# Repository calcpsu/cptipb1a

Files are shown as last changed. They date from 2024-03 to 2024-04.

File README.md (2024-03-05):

# CalcPack TI BP1A

A Li-Po battery replacement design for TI BP1A battery pack calculators - primarily TI-59. The original batteries had ~ 500mAh capacity (@3.6V: 1.8Wh), while modern Ni-MH replacements are typically ~1500mAh (@3.6V: 5.4Wh).

Li-Po has the advantage of far reduced self-discharge in comparison to Ni-MH, which is an advantage for an intermittently-used device. Even with similar mAh capacity, we can expect longer battery life.

Ni-MH / Ni-CD batteries are notorious for leaking. While Lithium Ion batteries are notorious for self-immolation, a well protected Li-Po battery (particularly in a low current application like this) should be able to be made very safe.

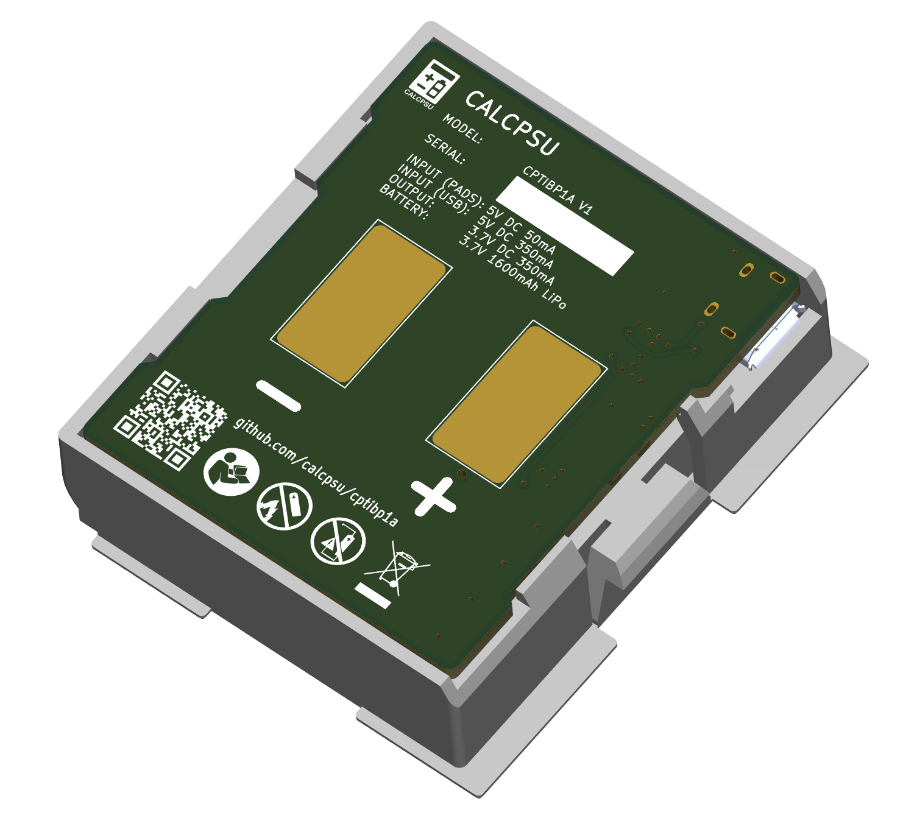
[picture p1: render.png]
Render of calcpack PCB


## Features / design goals:
- Direct replacement for a BP1A battery pack
- Compatible with existing charging circuit (although at a slow charge rate)
    - Provides adequate smoothing of rectified AC
    - Provides voltage clamping
- USB charging (when removed from calculator) at faster rate
- Protected from:
    - Overvoltage (USB and pads) at 2x rated voltage and current (IATA requirement)
    - Overcharging (4.2V)
    - Over-discharge (3.1V shutdown, 2.5V cutoff in battery pack)
    - Short circuit and overcurrent (again for IATA requirement)
- Minimum idle/quiescent current to maximise charge time
- Capable of operating TI-59 including card reader
- Similar or higher capacity than typical Ni-MH altenative (1500mAh @ 3.7V [5.55Wh])
  
## License

This work is licensed under a
[Creative Commons Attribution-NonCommercial-ShareAlike 4.0 International License][cc-by-nc-sa].

[][cc-by-nc-sa]

[cc-by-nc-sa]: http://creativecommons.org/licenses/by-nc-sa/4.0/
[cc-by-nc-sa-image]: https://licensebuttons.net/l/by-nc-sa/4.0/88x31.png
[cc-by-nc-sa-shield]: https://img.shields.io/badge/License-CC%20BY--NC--SA%204.0-lightgrey.svg

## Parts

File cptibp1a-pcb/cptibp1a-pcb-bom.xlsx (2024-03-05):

Id | Designator | Footprint | Quantity | Designation | Supplier and ref | Column1 | _1 | MPN
1 | U1 | SOT-23-5_TI_DBV5 | 1 | NCP360SNT |  |  |  | NCP360SNT1G
2 | F1 | Fuse_1210_3225Metric | 1 | 0ZCJ0050AF2E |  |  |  | 0ZCJ0050AF2E
3 | Q2 | SOT-23 | 1 | AO3413 |  |  |  | AO3413
4 | C6,C7 | CP_Elec_8x10.5 | 2 | 1000u/10V |  |  |  | EEE-FT1A102GP
5 | D2 | LED_0805_2012Metric | 1 | RED |  |  |  | B1701USD-20D000114U1930
6 | Q1 | SOT-23 | 1 | 2N7002 |  |  |  | DMG2302U-7
7 | C4 | C_0805_2012Metric | 1 | 4u7 |  |  |  | CL21A475KAQNNNE
8 | R2 | R_0805_2012Metric | 1 | 1k8
9 | R4 | R_0805_2012Metric | 1 | 3k |  |  |  | RC0805FR-073KL
10 | R5,R1 | R_0805_2012Metric | 2 | 10k |  |  |  | RC0805FR-0710KL
11 | C1 | C_0805_2012Metric | 1 | 1u |  |  |  | CL21B105KAFNNNE
12 | U5 | SOT-23-5_TI_DBV5 | 1 | MAX40203AUK |  |  |  | MAX40203AUK+T
13 | U3 | SOT-23-6_TI_DBV6 | 1 | BQ21040 |  |  |  | BQ21040DBVR
14 | D1 | D_SOD-123 | 1 | PMEG40T10ERX |  |  |  | PMEG40T10ERX
15 | J1 | AMPHENOL_10118194-0001LF | 1 | 10118194-0001LF |  |  |  | 10118194-0001LF
16 | C2 | C_0805_2012Metric | 1 | 10u |  |  |  | CL21A106KAYNNNE
17 | BT1 | JST_SH_BM03B-SRSS-TB_1x03-1MP_P1.00mm_Vertical | 1 | LiPo |  |  |  | BM03B-SRSS-TB
18 | U2 | SOT-23-3 | 1 | APX809S-31SA |  |  |  | APX809S-31SA-7
19 | R3 | R_0805_2012Metric | 1 | 8k66 |  |  |  | RC0805FR-078K66L
20 | U4 | SOT-23-3 | 1 | APX810S-44SA |  |  |  | APX810S-44SA
21 | D3 | D_SMA | 1 | 5V6/3W |  |  |  | 3SMAJ5919B-TP
22 | J3 | PAD_6x15 | 1 | PAD-
23 | J2 | PAD_6x15 | 1 | PAD+

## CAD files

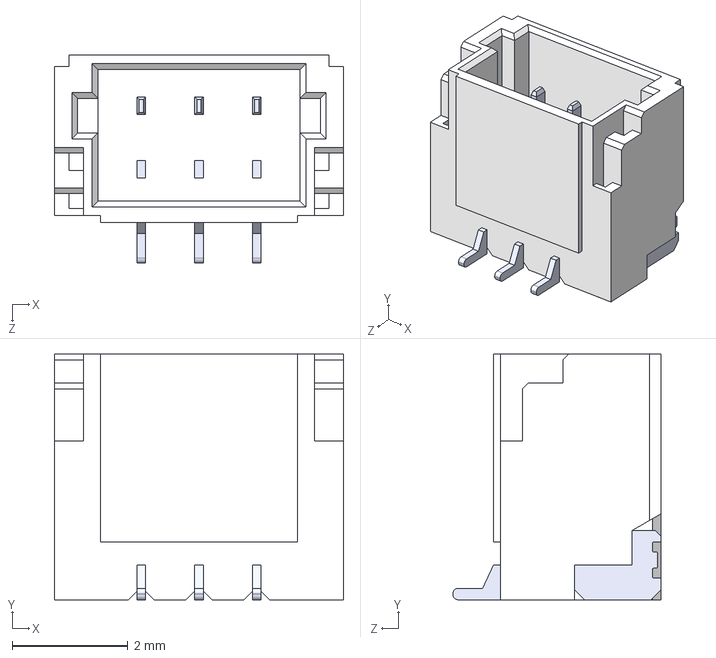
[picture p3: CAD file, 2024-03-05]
cptibp1a-pcb/3d/BM03B-SRSS-TB.STEP
5.00 x 4.25 x 3.60 mm

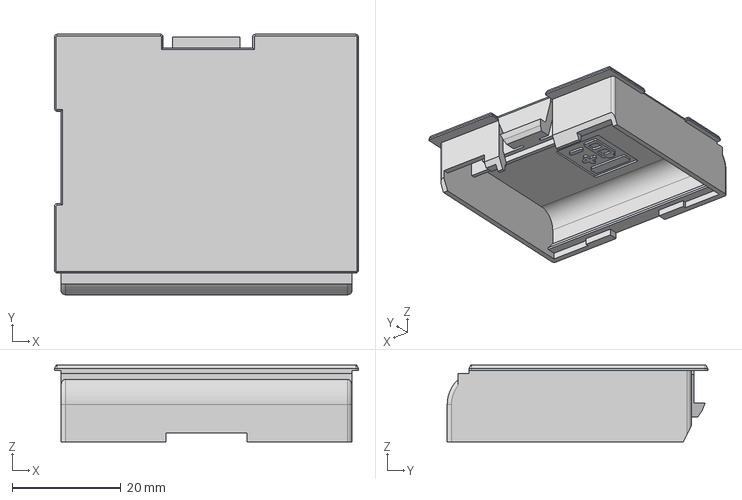
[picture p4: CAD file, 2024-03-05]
cptibp1a-pcb/cptibp1a-enclosure.step
56.0 x 48.0 x 14.1 mm

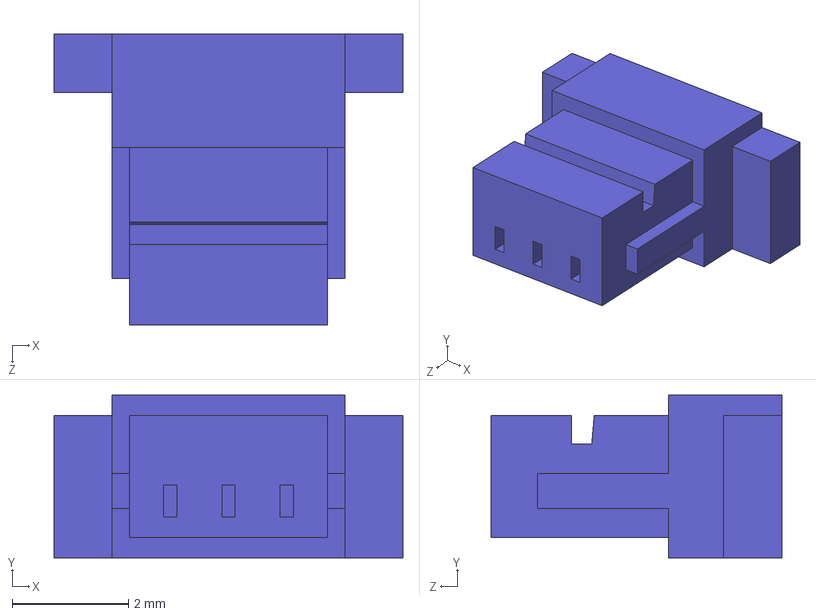
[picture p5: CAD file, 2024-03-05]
cptibp1a-pcb/3d/SHR-03V-S-B.STEP
6.00 x 2.80 x 5.00 mm

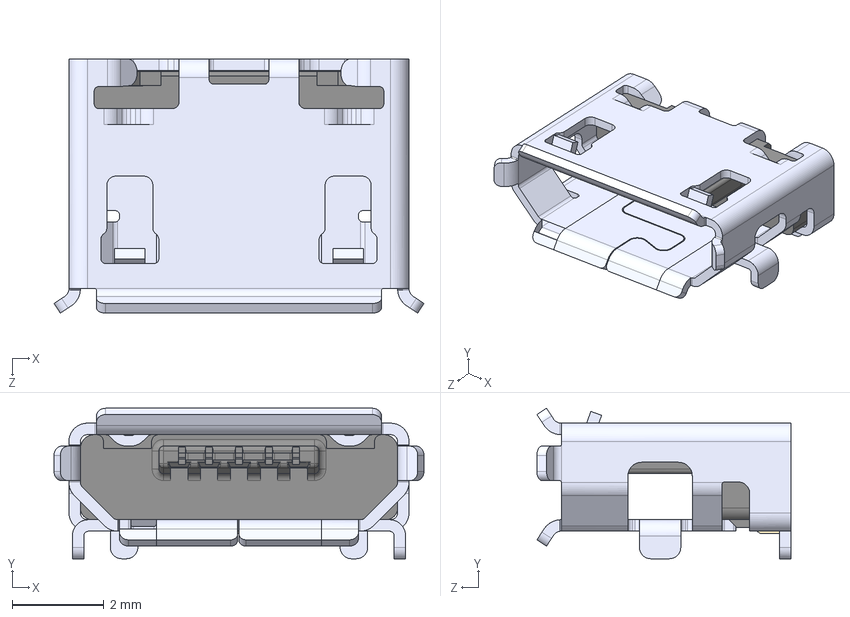
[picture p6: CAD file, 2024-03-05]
cptibp1a-pcb/3d/10118194-0001LF.step
8.05 x 3.27 x 5.53 mm

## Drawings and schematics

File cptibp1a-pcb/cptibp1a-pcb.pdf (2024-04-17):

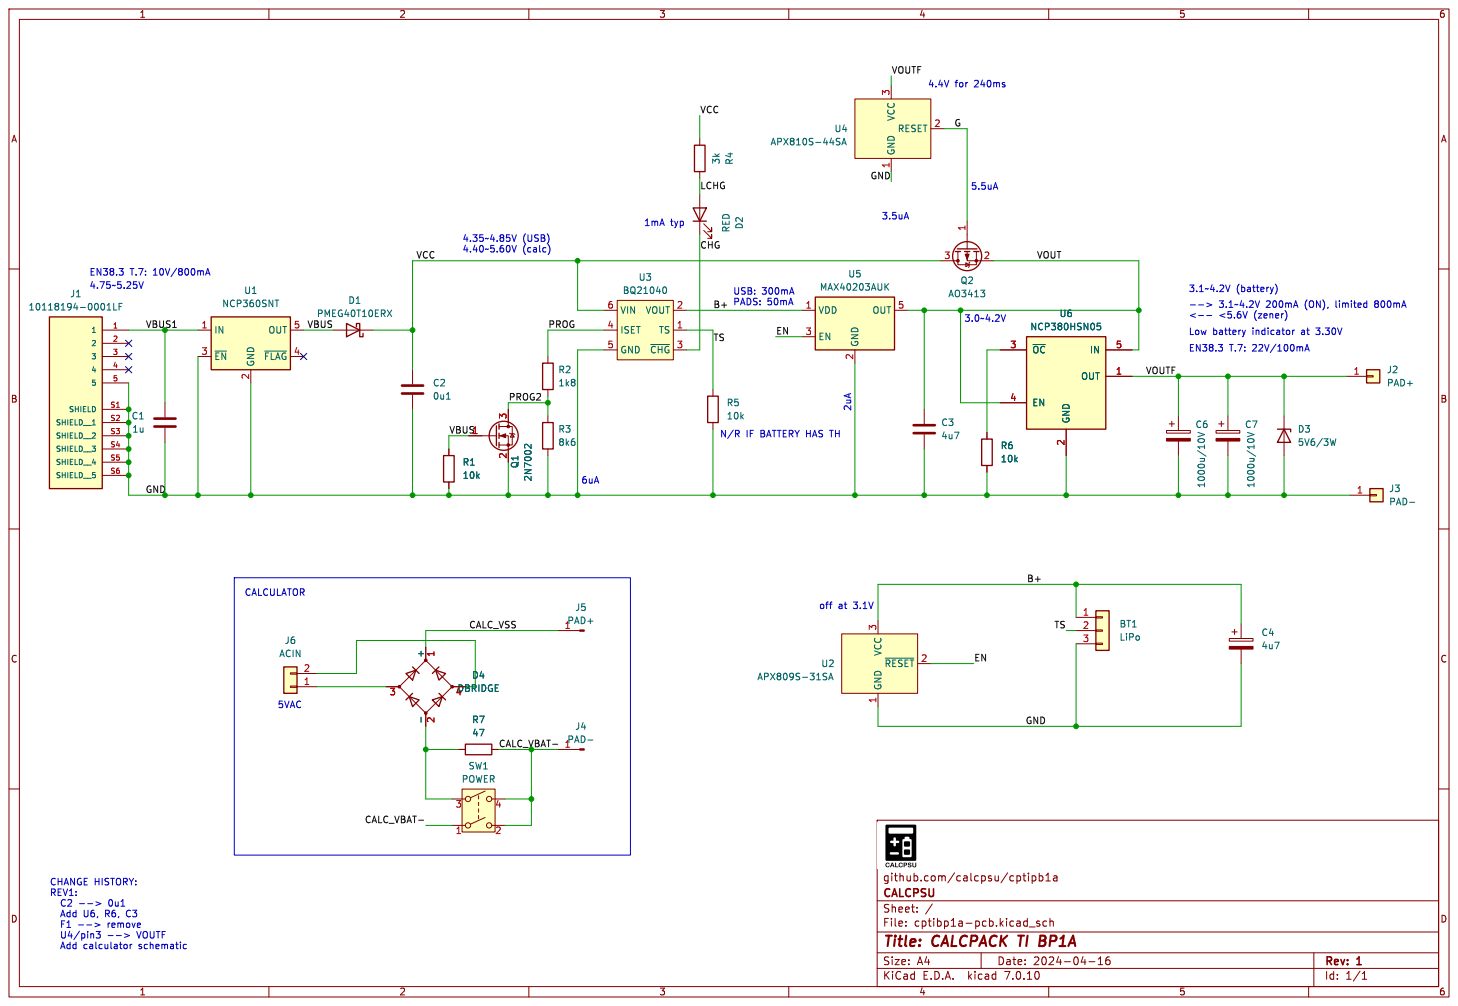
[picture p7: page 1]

github.com/calcpsu/cptipb1a
File: cptibp1a-pcb.kicad_sch Sheet: / CALCPSU

Id: 1/1 Title: CALCPACK TI BP1A

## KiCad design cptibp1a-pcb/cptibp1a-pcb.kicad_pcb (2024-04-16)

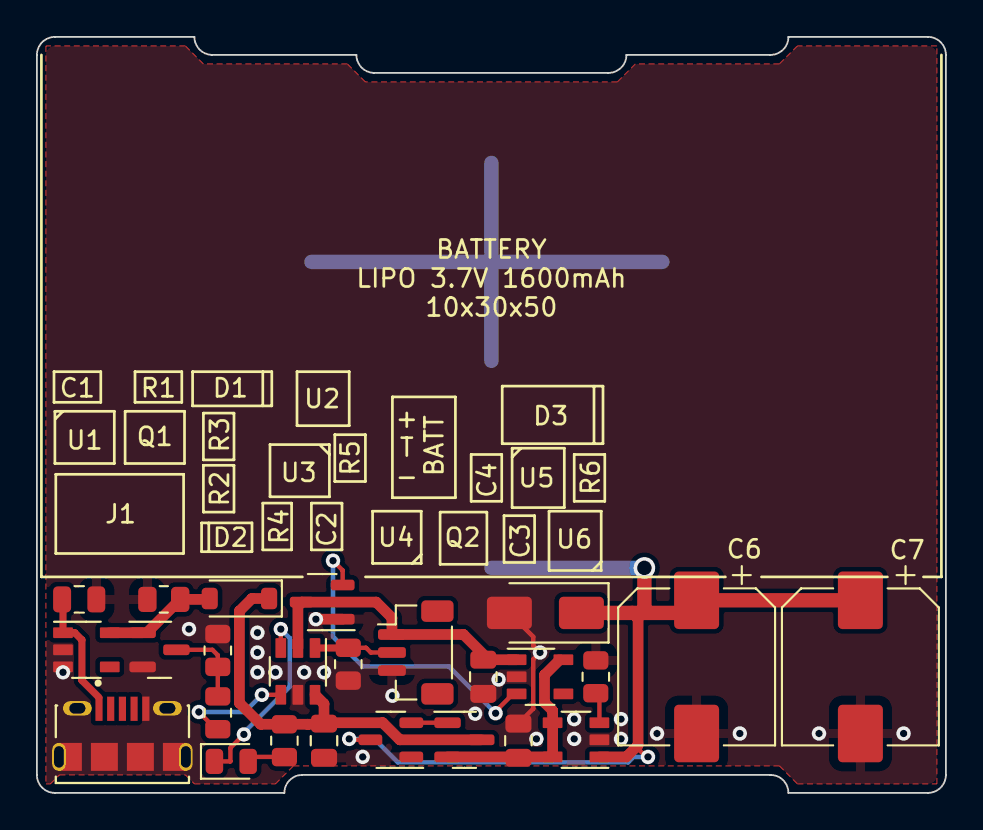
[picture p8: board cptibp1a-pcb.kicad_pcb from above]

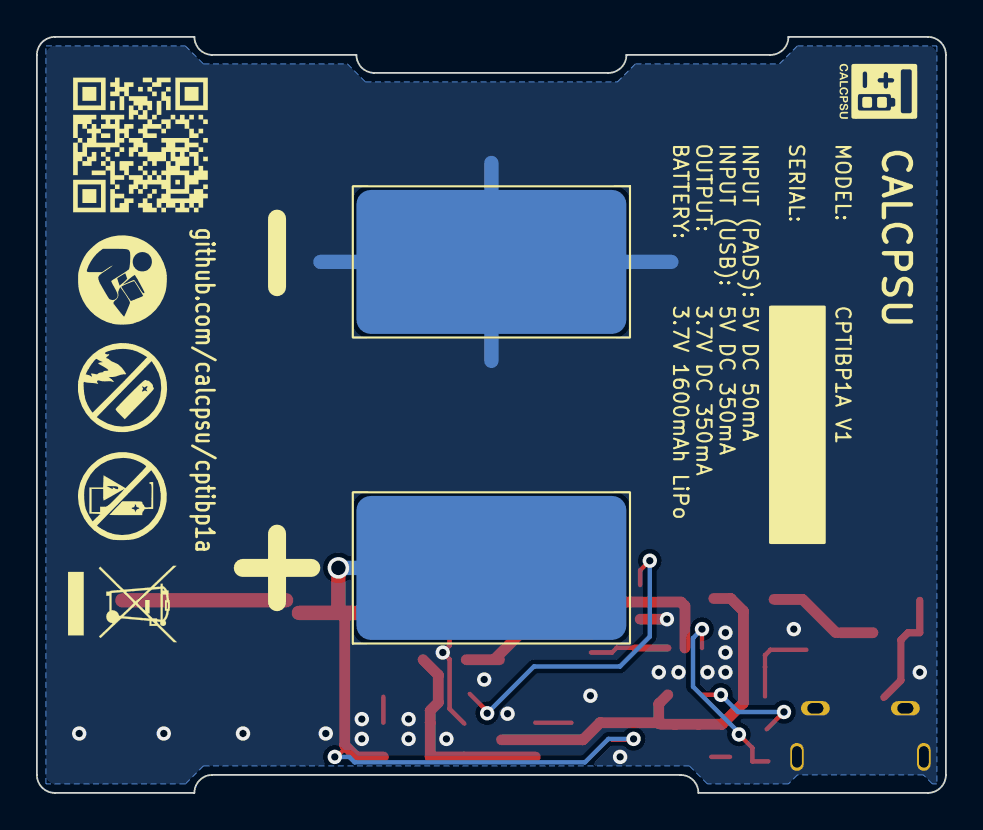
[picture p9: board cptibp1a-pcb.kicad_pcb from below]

Board: 2 copper layers, 50.5 x 42.0 mm, 27 parts (2 on the bottom side), 15 nets.

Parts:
BT1: LiPo; JST_SH_BM03B-SRSS-TB_1x03-1MP_P1.00mm_Vertical
C1: 1u; C_0805_2012Metric
C2: 0u1; C_0805_2012Metric
C3, C4: 4u7; C_0805_2012Metric
C6, C7: 1000u/10V; CP_Elec_8x10.5
D1: PMEG40T10ERX; D_SOD-123
D2: RED; LED_0805_2012Metric
D3: 5V6/3W; D_SMA
J1: 10118194-0001LF; AMPHENOL_10118194-0001LF
J2: PAD+; PAD_8x15
J3: PAD-; PAD_8x15
Q1: 2N7002; SOT-23
Q2: AO3413; SOT-23
R1, R5, R6: 10k; R_0805_2012Metric
R2: 1k8; R_0805_2012Metric
R3: 8k6; R_0805_2012Metric
R4: 3k; R_0805_2012Metric
U1: NCP360SNT; SOT-23-5_TI_DBV5
U2: APX809S-31SA; SOT-23-3
U3: BQ21040; SOT-23-6_TI_DBV6
U4: APX810S-44SA; SOT-23-3
U5: MAX40203AUK; SOT-23-5_TI_DBV5
U6: NCP380HSN05; SOT-23-5_TI_DBV5

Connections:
/B+: BT1.1, C4.1, U2.3 (VCC), U3.2 (VOUT), U5.1 (VDD)
/CHG: D2.1 (K), U3.3 (~CHG)
/EN: U2.2 (~RESET), U5.3 (EN)
/G: Q2.1 (G), U4.2 (RESET)
/GND: BT1.3, C1.2, C2.2, C3.2, C4.2, C6.2, C7.2, D3.2 (A), J1.5, J1.S1 (SHIELD), J1.S2 (SHIELD__1), J1.S3 (SHIELD__2), J1.S4 (SHIELD__3), J1.S5 (SHIELD__4), J1.S6 (SHIELD__5), J3.1, Q1.2 (S), R1.1, R3.1, R5.1, R6.1, U1.2 (GND), U1.3 (~EN), U2.1 (GND), U3.5 (GND), U4.1 (GND), U5.2 (GND), U6.2 (GND)
/LCHG: D2.2 (A), R4.1
/PROG: R2.2, U3.4 (ISET)
/PROG2: Q1.3 (D), R2.1, R3.2
/TS: BT1.2, R5.2, U3.1 (TS)
/VBUS: D1.2 (A), Q1.1 (G), R1.2, U1.5 (OUT)
/VBUS1: C1.1, J1.1, U1.1 (IN)
/VCC: C2.1, D1.1 (K), Q2.3 (D), R4.2, U3.6 (VIN)
/VOUT: C3.1, Q2.2 (S), U5.5 (OUT), U6.4 (EN), U6.5 (IN)
/VOUTF: C6.1, C7.1, D3.1 (K), J2.1, U4.3 (VCC), U6.1 (OUT)
unnamed: R6.2, U6.3 (~OC)

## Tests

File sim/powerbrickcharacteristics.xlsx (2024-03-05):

RL(ohm) | i(A) | V(V) | Vs(V) | Rs(ohm) | i(mA) | Vpredicted(V) | Vpk
inf | 0 | 6.62 | 6.62 | 6.08 | 0 | 6.62 | 9.362093783
100 | 0.061 | 6.1 |  |  | 50 | 6.316
50 | 0.1162 | 5.81 |  |  | 100 | 6.012
33 | 0.1675757576 | 5.53 |  |  | 150 | 5.708
25 | 0.212 | 5.3 |  |  | 200 | 5.404
 |  |  |  |  | 250 | 5.1

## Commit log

2024-04-16 Rev1 update (minor)
    [cptibp1a-pcb-B_Cu.gbr, cptibp1a-pcb-B_Mask.gbr, cptibp1a-pcb-B_Paste.gbr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]
2024-04-16 Move power connector (battery clash reduce)
    [cptibp1a-pcb-B_Cu.gbr, cptibp1a-pcb-B_Mask.gbr, cptibp1a-pcb-B_Paste.gbr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]
2024-04-17 remove nonpop
    [cptibp1a-pcb.kicad_sch]
